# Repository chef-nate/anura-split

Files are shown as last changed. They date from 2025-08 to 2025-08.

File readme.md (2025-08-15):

# anura-split

## 34 (+2) key split mechanical keyboard featuring

- hotswap choc v1 switches
- fully reversible pcb
- bluetooth support with nice!nano
- support for nice!view
- support for cirque trackpad (requires breakout board off nice!view headers)
- rotary scroll encoder switch (SW18, outer thumb cluster key)

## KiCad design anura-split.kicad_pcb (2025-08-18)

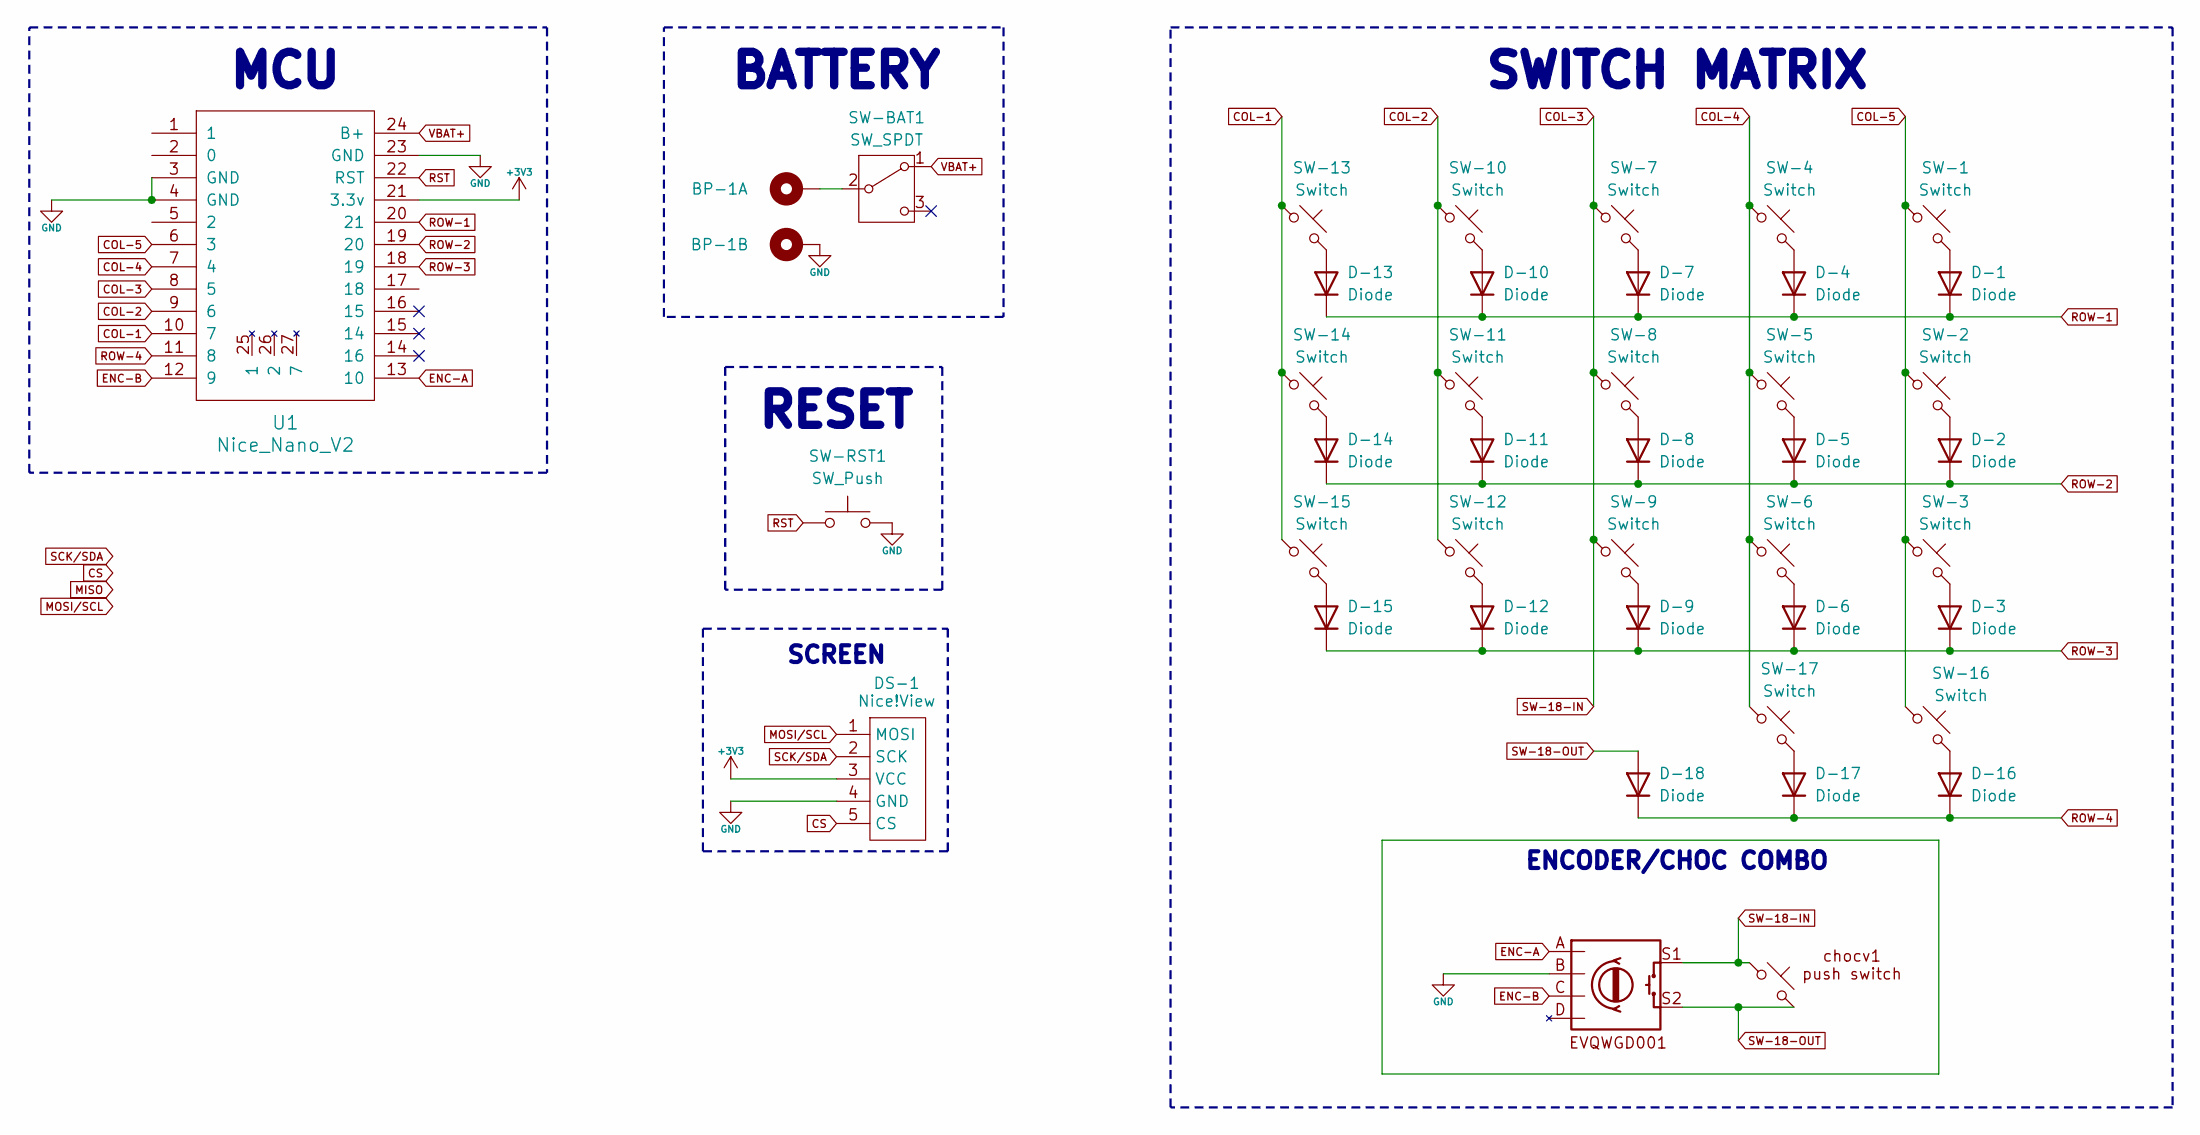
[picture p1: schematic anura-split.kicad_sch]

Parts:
BP-1: BatteryPad
CombChocEncoder1: hotswap_chocv1_combined_EVQWGD001
D-1, D-2, D-3, D-4, D-5, D-6, D-7, D-8, D-9, D-10, D-11, D-12, D-13, D-14, D-15, D-16, D-17, D-18: Diode; SOD123 Reversible
DS-1: Nice!View; nice!view_rev2
SW-1, SW-2, SW-3, SW-4, SW-5, SW-6, SW-7, SW-8, SW-9, SW-10, SW-11, SW-12, SW-13, SW-14, SW-15, SW-16, SW-17: Switch; Choc_Hotswap_Reversible
SW-BAT1: SW_SPDT; SW-TH_MSK12C02
SW-RST1: SW_Push; SW_PUSH_SPST
U1: Nice_Nano_V2; nice!nano_facedown

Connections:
+3V3: DS-1.3 (VCC), U1.21 (3.3v)
COL-1: SW-13.1, SW-14.1, SW-15.1, U1.10 (7)
COL-2: SW-10.1, SW-11.1, SW-12.1, U1.9 (6)
COL-3: CombChocEncoder1.1, CombChocEncoder1.S1, SW-7.1, SW-8.1, SW-9.1, U1.8 (5)
COL-4: SW-4.1, SW-5.1, SW-6.1, SW-17.1, U1.7 (4)
COL-5: SW-1.1, SW-2.1, SW-3.1, SW-16.1, U1.6 (3)
CS: DS-1.5 (CS)
ENC-A: CombChocEncoder1.A, U1.13 (10)
ENC-B: CombChocEncoder1.C, U1.12 (9)
GND: BP-1.2, CombChocEncoder1.B, DS-1.4 (GND), SW-RST1.2, U1.3 (GND), U1.4 (GND), U1.23 (GND)
MOSI/SCL: DS-1.1 (MOSI)
unnamed: D-1.2 (A), SW-1.2
unnamed: D-2.2 (A), SW-2.2
unnamed: D-3.2 (A), SW-3.2
unnamed: D-4.2 (A), SW-4.2
unnamed: D-5.2 (A), SW-5.2
unnamed: D-6.2 (A), SW-6.2
unnamed: D-7.2 (A), SW-7.2
unnamed: D-8.2 (A), SW-8.2
unnamed: D-9.2 (A), SW-9.2
unnamed: D-10.2 (A), SW-10.2
unnamed: D-11.2 (A), SW-11.2
unnamed: D-12.2 (A), SW-12.2
unnamed: D-13.2 (A), SW-13.2
unnamed: D-14.2 (A), SW-14.2
unnamed: D-15.2 (A), SW-15.2
unnamed: D-16.2 (A), SW-16.2
unnamed: D-17.2 (A), SW-17.2
unnamed: BP-1.1, SW-BAT1.2 (B)
ROW-1: D-1.1 (K), D-4.1 (K), D-7.1 (K), D-10.1 (K), D-13.1 (K), U1.20 (21)
ROW-2: D-2.1 (K), D-5.1 (K), D-8.1 (K), D-11.1 (K), D-14.1 (K), U1.19 (20)
ROW-3: D-3.1 (K), D-6.1 (K), D-9.1 (K), D-12.1 (K), D-15.1 (K), U1.18 (19)
ROW-4: D-16.1 (K), D-17.1 (K), D-18.1 (K), U1.11 (8)
RST: SW-RST1.1, U1.22 (RST)
SCK/SDA: DS-1.2 (SCK)
SW-18-OUT: CombChocEncoder1.2, CombChocEncoder1.S2, D-18.2 (A)
VBAT+: SW-BAT1.1 (A), U1.24 (B+)

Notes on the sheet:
SCREEN
RESET
MCU
ENCODER/CHOC COMBO
BATTERY
SWITCH MATRIX

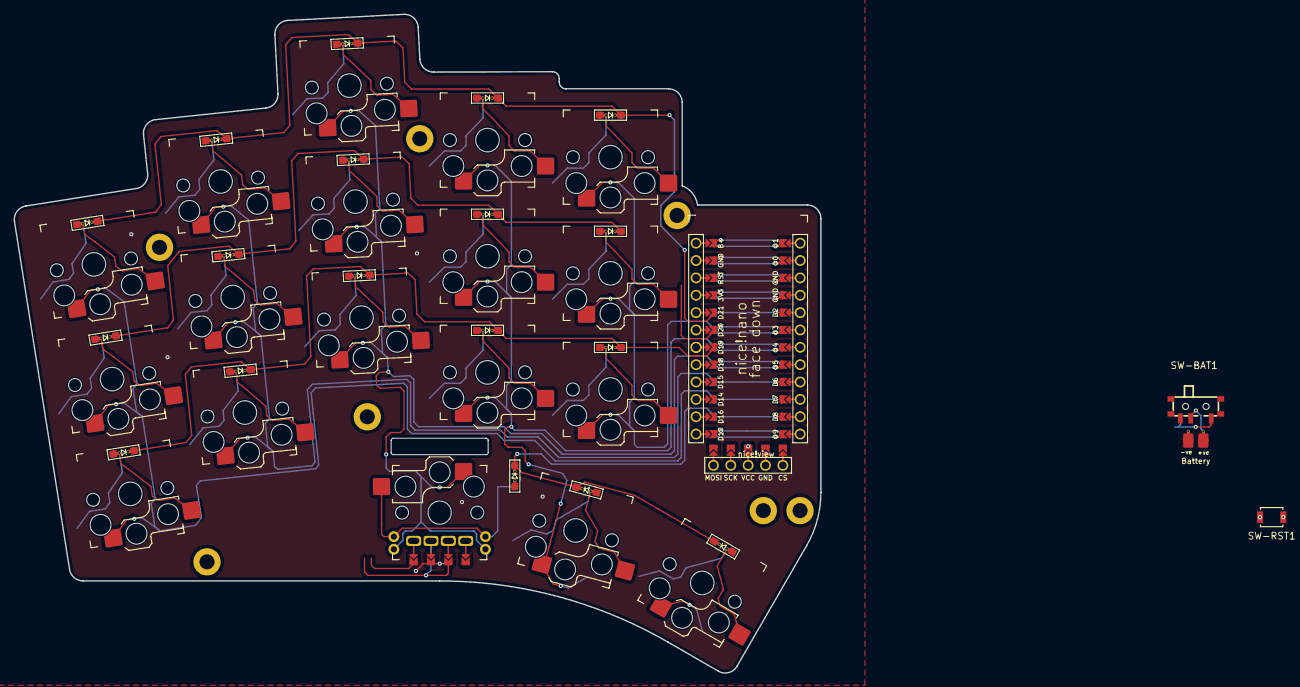
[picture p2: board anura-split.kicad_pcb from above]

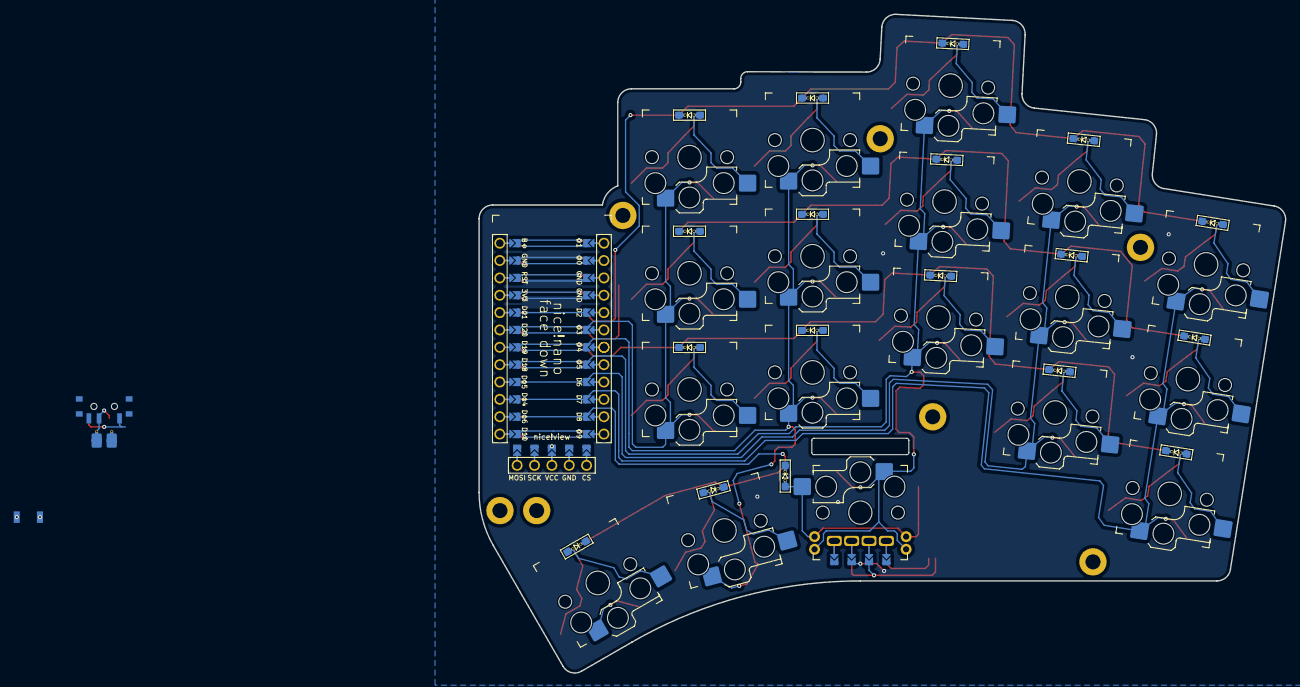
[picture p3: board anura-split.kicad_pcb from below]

Board: 2 copper layers, 118.0 x 96.4 mm, 41 parts (19 on the bottom side), 34 nets.

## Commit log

2025-08-15 initial commit
    schematic designed and basic pcb design started. still wip
    [anura-split.kicad_pcb, anura-split.kicad_sch]
2025-08-15 lib-anura updates
    added and updated variety of symbols in schematic library, to get rid of
    dependencies
    [anura-split.kicad_sch]
2025-08-15 3d models added
    removed dependencies for 3d models and instead integrated directly into
    project
    [anura-split.kicad_pcb]
2025-08-16 trace routing + silkscreen design
    [anura-split.kicad_pcb, anura-split.kicad_sch]
2025-08-18 routing + schematic changes
    mcu nets reorganised to suit trace routing better, and more traces
    routed
    [anura-split.kicad_pcb, anura-split.kicad_sch]
